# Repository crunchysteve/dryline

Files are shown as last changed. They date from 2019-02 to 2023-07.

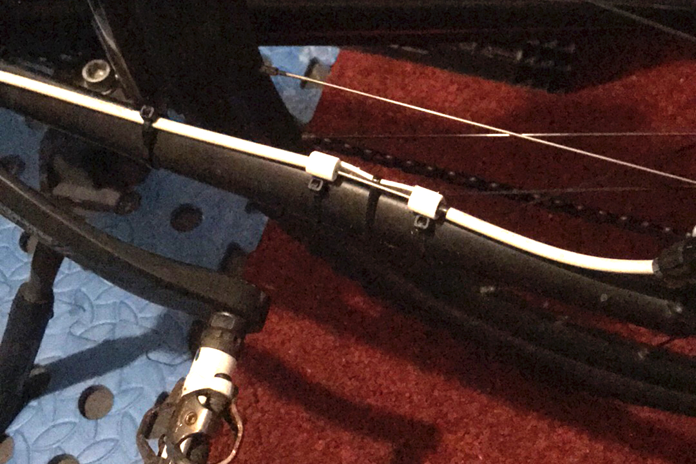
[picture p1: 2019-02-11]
dryline1.jpg

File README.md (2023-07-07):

[Discuss the code or seek support for any of my code projects at my discussions page.](https://github.com/crunchysteve/crunchysteve.github.io/discussions)
***

# dryline
Rear disk brake cable drain for touring and urban work bicycles fitted with mechanical disk brakes.

Cable pulled disk brakes, common on drop bar road, CX, touring and urban bicycles fill the rear cable up with gunge because of the "upside down" mount, inside the rear triangle. This SCAD file is a design for an inline cable drain which can be 3D printed and fitted inside the left-hand chainstay to stop water pooling in the cable below the bottom bracket.

Initially, Dryline was an attempt at a "manufacture on demand" product to supplement my income, but it seems that, while many in the cycle touring community think it's a good idea, few want to purchase and install one, so I've open sourced it here. A CNC could also be programmed to make this in aluminium, as well is it being easy to create an STL from the SCAD file, then g-code for your printer/CNC from the STL file.

Dryline is released to the public under a Creative Commons 4.0 licence, with attribution, non-commercial and share-alike conditions. Feel free to alter the code for the better, fork or otherwise use, provided my CC4 conditions are met.

I am still willing to make on demand for those who don't have a 3D printer or adequate CNC to make their own. Contact me via the Thingiverse page for Dryline. https://www.thingiverse.com/thing:3373400

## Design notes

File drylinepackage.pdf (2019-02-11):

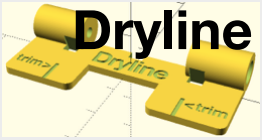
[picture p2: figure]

Mechanical disk brake freedom!

Keep mechanical
disk brake lines dry

The mechanical disk brake cable vent, gives you complete disk brake freedom!

Dryline helps to...
1. reduce water and dirt getting into your rear brake line on "inboard" rear disks, common to touring and urban bicycles,
2. dry the cable more quickly when water does get in.
3. provide a straighter path for the rear brake cable.

Dryline is intended for mechanical disk brake bicycles with inboard rear disks brakes mounted on the left chainstay, it isn't necessary for the front brake line or for seatstay mounted (outboard) disk brakes. Dryline is not compatible with hydraulic disk systems, other than cable actuated hydraulic road bike brakes.

We recommend fitting Dryline with a new rear cable set for best results.

Instructions inside.

Open here, with care -->

http://clunkerbike.com/

RRP AU$14.90

# Dryline Dryline

1. On the inside of the left chainstay, locate the brake hose guide. Lace the first ziptie through the guide, around the outside of the stay and the Dryline, as shown, then pull the ziptie down firmly but not too tight.

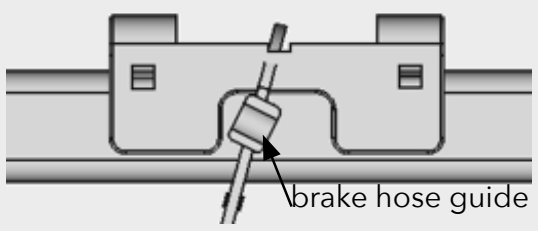
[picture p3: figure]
brake hose guide

2. Pass another 2 zipties through the holes in the Dryline, loop them around the stay and tighten firmly, as shown.

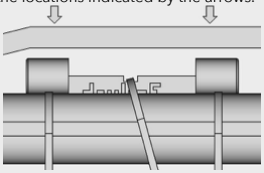
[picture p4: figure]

3. Place the brake hose across the Dryline cable stops and cut the hose at the locations indicated by the arrows.
4. Insert the hose ends into the Dryline.

Here at Clunkerbike, we recommend running mechanical brake lines above

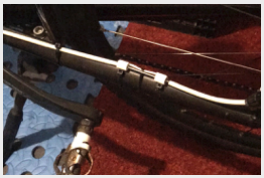
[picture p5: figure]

the bottom bracket (where possible) and along the top of the stay. This helps reduce the accumulation of water in the brake line. Here is Dryline number 1 on the Clunkerbike "company car" to give you a real world example.

5. Feed the cable through the brake lever, hose, and Dryline to the brake. Adjust and lock off the brake. Tie the brake line to the chainstay with zipties, as appropriate.

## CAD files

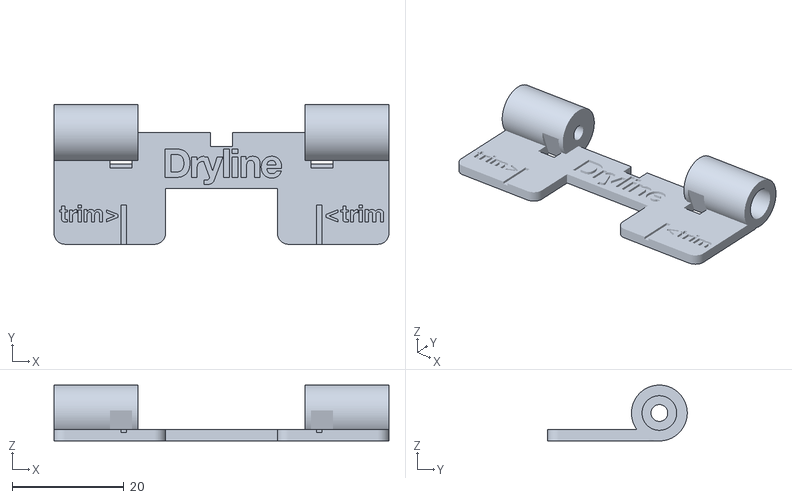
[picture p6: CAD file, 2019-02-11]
Dryline_v1.2.stl
60.0 x 25.0 x 10.0

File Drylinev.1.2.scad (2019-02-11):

// Dryline - mechanical disk brake cable vent

$fn=100; // set smoothness (larger = smoother)

// commence Dryline
difference() {
    union() {
        body();
        mirror() body();
    }
    
    // Emboss front lettering and markings
    // Emboss branding
    translate([0,-3,1]) {
        linear_extrude(height = 0.6, convexity = 10, slices = 20, scale = 1) {
            text(text = "Dryline", size = 5, 
            font = ".Helvetica Neue   DeskInterface:style=Bold",
            halign = "center", valign = "baseline", spacing = 1, 
            script = "latin", direction = "ltr");
        }
    }
    // Emboss trimming markings
    translate([-23.5,-11,1]) {
        linear_extrude(height = 0.6, convexity = 10, slices = 20, scale = 1) {
            text(text = "trim>", size = 3, 
            font = ".Helvetica Neue   DeskInterface:style=Bold",
            halign = "center", valign = "baseline", spacing = 1.15, 
            script = "latin", direction = "ltr");
        }
    }
    translate([24,-11,1]) {
        linear_extrude(height = 0.6, convexity = 10, slices = 20, scale = 1) {
            text(text = "<trim", size = 3, 
            font = ".Helvetica Neue   DeskInterface:style=Bold",
            halign = "center", valign = "baseline", spacing = 1.15, 
            script = "latin", direction = "ltr");
        }
    }
}



module body() {
    difference() {
        union() {
            // backing plate
            translate([5.9,0,0.5]) cube([12,10,2], center=true);

            translate([20,-5,0]) {
                minkowski() {
                    cube([16,16,1], center=true);
                    cylinder(r=2,h=1);
                }
            }
    
            //cable stop
            translate([15,5,4.5]) rotate([0,90,0]) cylinder(h=15, d=10);
        }

    // cable gland
        translate([12,5,4.5]) rotate([0,90,0]) cylinder(h=20,d=3);
    // sheath gland
        translate([18,5,4.5]) rotate([0,90,0]) cylinder(h=13,d=6.2);
    // ziptie ducts
        translate([18,0.5,0]) rotate([20,0,0]) cube([4,2.5,15], center=true);
        translate([0,3.8,0]) cube([4,2.5,15], center=true);
    // trimming marks
        translate([17,-15,1]) cube([1,7,1]);
    }
}
